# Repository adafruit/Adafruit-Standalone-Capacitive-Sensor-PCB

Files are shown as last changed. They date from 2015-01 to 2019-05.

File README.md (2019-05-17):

# Adafruit Standalone Capacitive Sensor PCBs

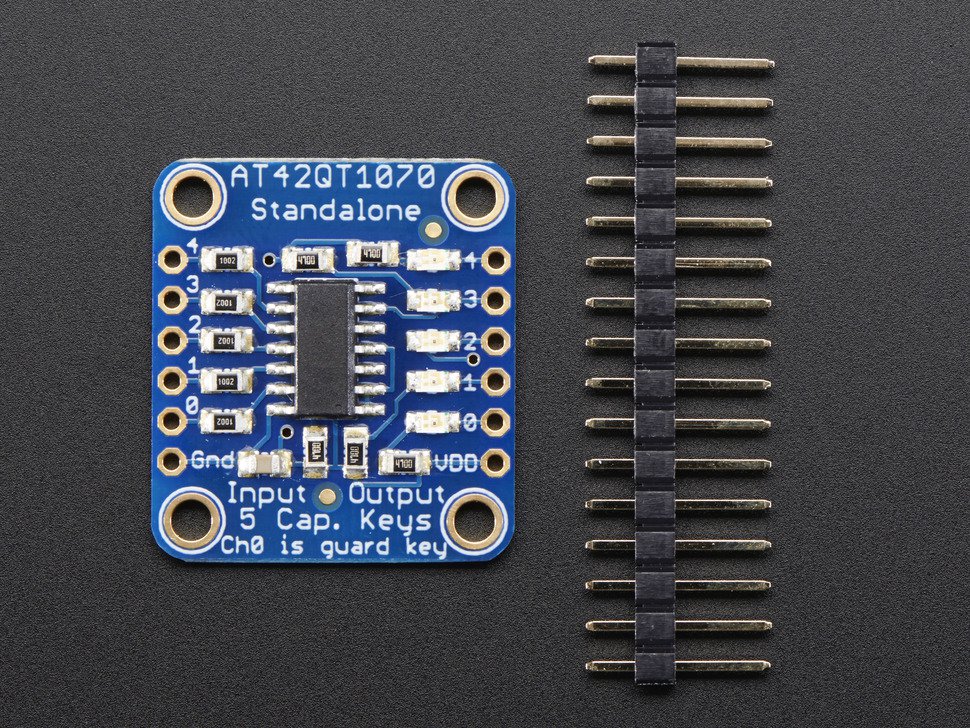
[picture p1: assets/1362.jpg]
&nbsp; 
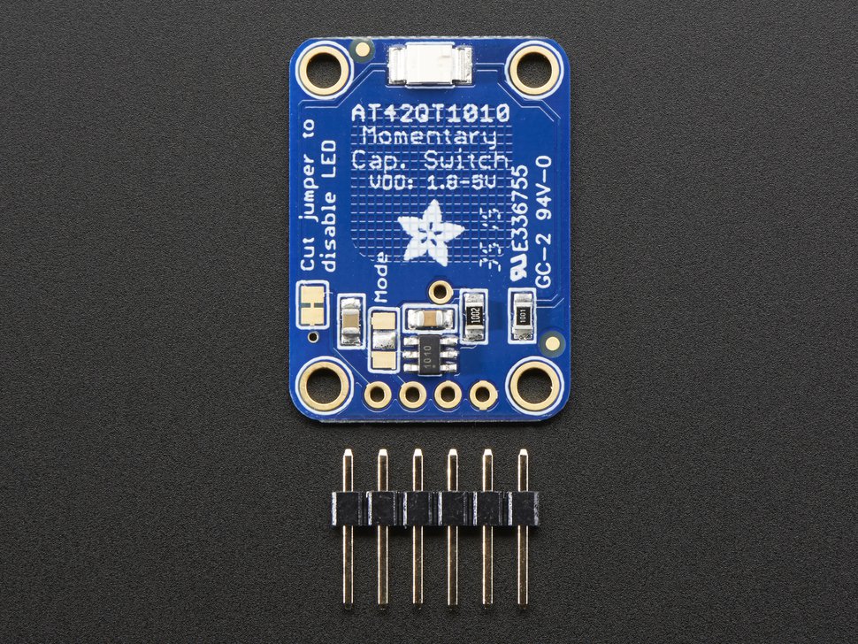
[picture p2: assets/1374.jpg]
&nbsp; 
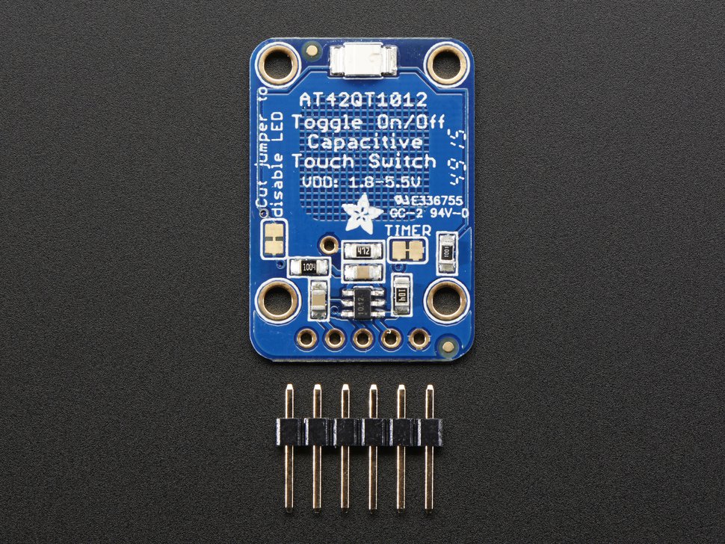
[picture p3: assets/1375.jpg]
<br />

Breakout boards for stand-alone capacitive touch sensors. These are the simplest ways to create projects with capacitive touch. No microcontroller is required here - just power with 1.8 to 5.5VDC. When a capacitive load is detected (e.g. a person touches one of the conductive contacts) the corresponding LED lights up and the output pin goes low. 

Format is EagleCAD schematic and board layout

For more details, check out the product pages at

-----> http://www.adafruit.com/products/1362

-----> http://www.adafruit.com/products/1374

-----> http://www.adafruit.com/products/1375

### License

Adafruit invests time and resources providing this open source design, please support Adafruit and open-source hardware by purchasing products from [Adafruit](https://www.adafruit.com)!

All text above must be included in any redistribution

Designed by Limor Fried/Ladyada for Adafruit Industries.
Creative Commons Attribution/Share-Alike, all text above must be included in any redistribution. 
See license.txt for additional information.

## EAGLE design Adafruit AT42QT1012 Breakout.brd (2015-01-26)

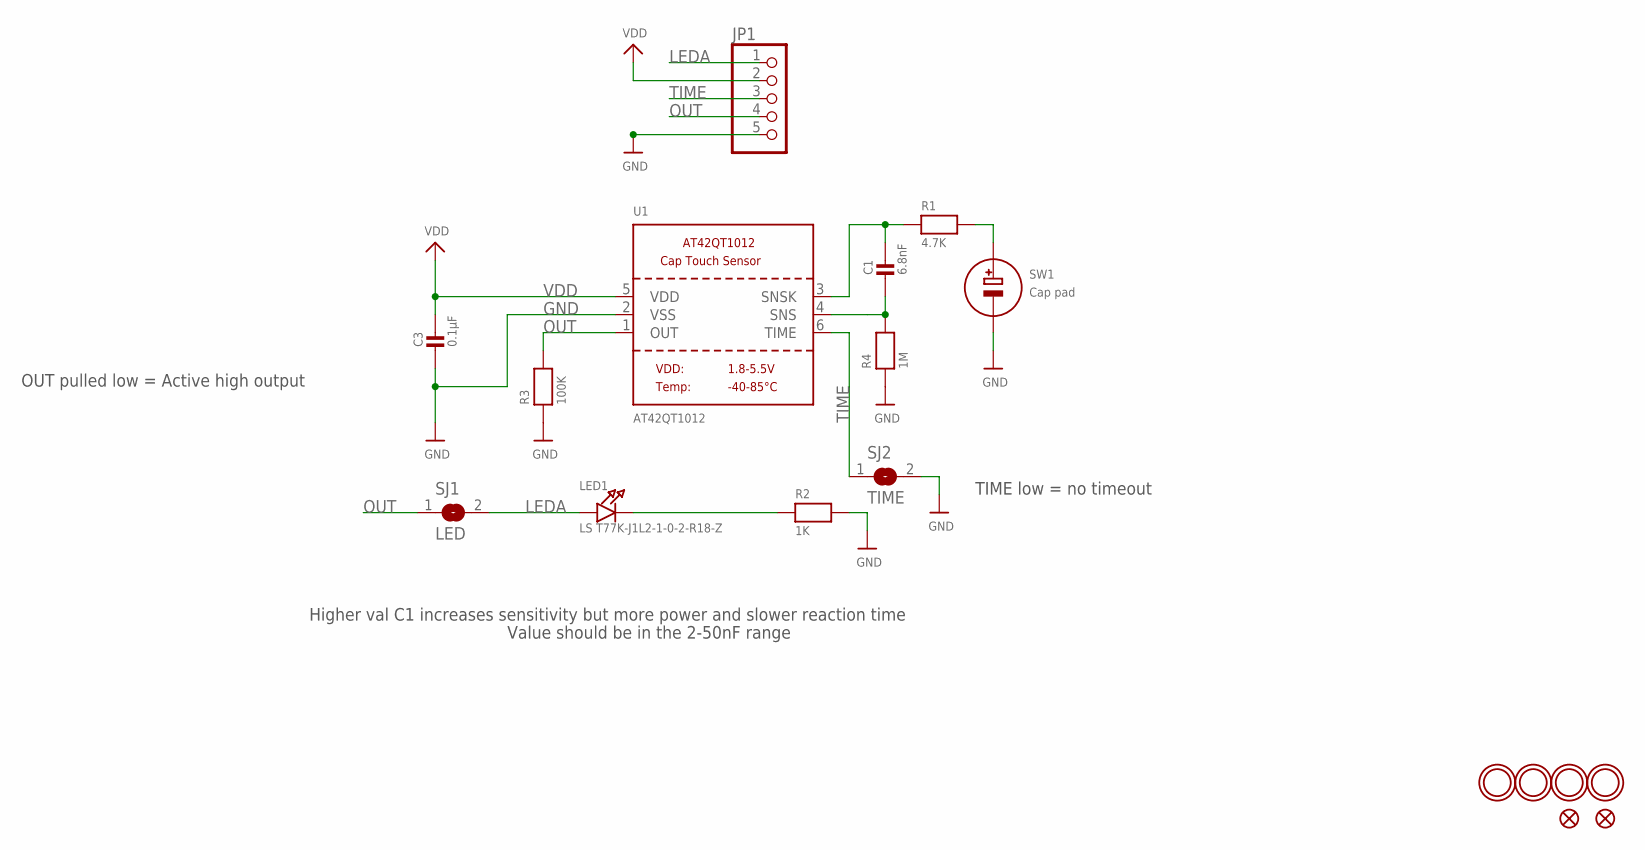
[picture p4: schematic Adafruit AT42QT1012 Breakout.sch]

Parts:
C1: 6.8nF; _0805
C3: 0.1µF; _0805
FID1, FID2: FIDUCIAL""; FIDUCIAL_1MM
JP1: HEADER-1X570MIL; 1X05_ROUND_70
LED1: LS T77K-J1L2-1-0-2-R18-Z; PLCC2_REVMOUNT
R1: 4.7K; _0805
R2: 1K; _0805
R3: 100K; _0805
R4: 1M; _0805
SJ1: LED; SOLDERJUMPER_CLOSEDWIRE
SJ2: TIME; SOLDERJUMPER_CLOSEDWIRE
SW1: Cap pad; CAPTOUCH_SIMPLE_12.5MM
U1: AT42QT1012; SOT23-6
U$6, U$9, U$10, U$11: MOUNTINGHOLE2.5; MOUNTINGHOLE_2.5_PLATED

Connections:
GND: C3.2, JP1.5, R2.2, R3.1, R4.1, SJ2.2, SW1.G (-), U1.2 (VSS)
LEDA: JP1.1, LED1.A, SJ1.2
unnamed: R1.2, SW1.E (+)
unnamed: C1.2, R4.2, U1.4 (SNS)
unnamed: C1.1, R1.1, U1.3 (SNSK)
unnamed: LED1.K (C), R2.1
OUT: JP1.4, R3.2, SJ1.1, U1.1 (OUT)
TIME: JP1.3, SJ2.1, U1.6 (TIME)
VDD: C3.1, JP1.2, U1.5 (VDD)

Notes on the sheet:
Higher val C1 increases sensitivity but more power and slower reaction time
Value should be in the 2-50nF range
OUT pulled low = Active high output
TIME low = no timeout

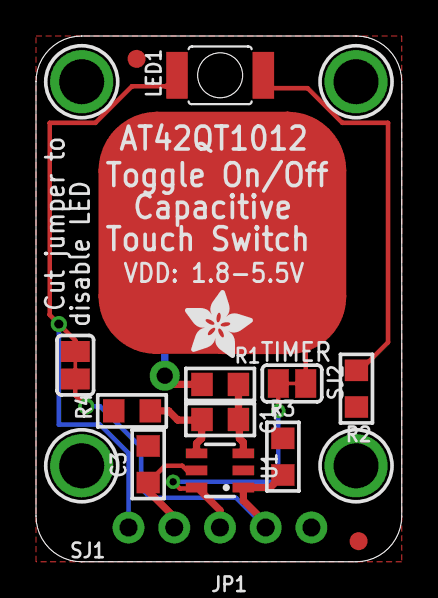
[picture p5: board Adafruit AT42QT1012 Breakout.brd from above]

Board: 2 copper layers, 20.3 x 29.2 mm, 19 parts (1 on the bottom side), 9 nets.

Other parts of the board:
U$12: ADAFRUIT_3.5MM

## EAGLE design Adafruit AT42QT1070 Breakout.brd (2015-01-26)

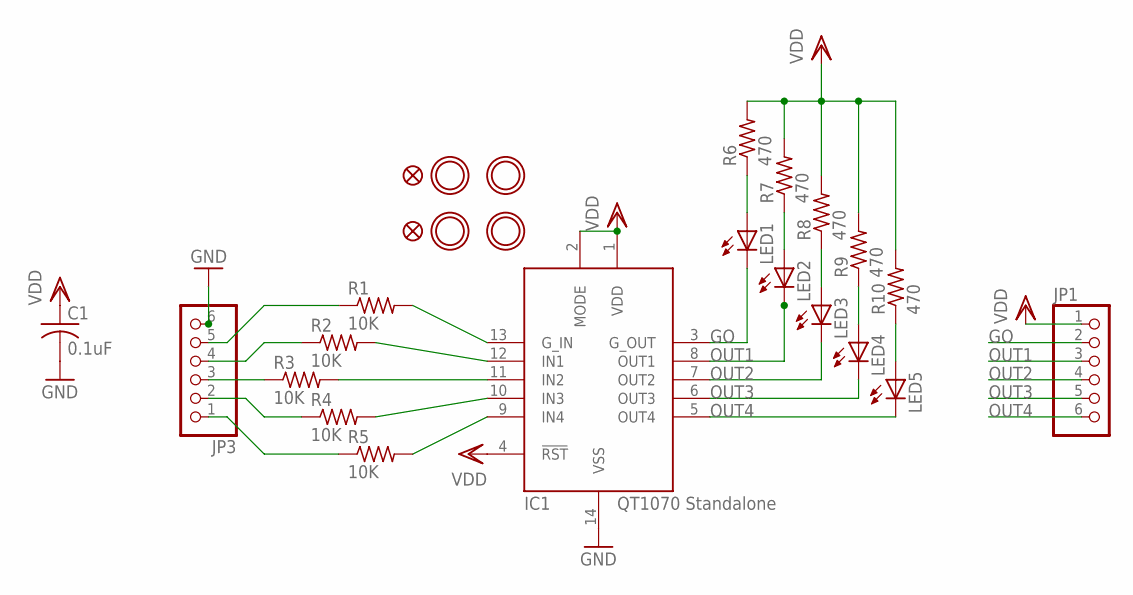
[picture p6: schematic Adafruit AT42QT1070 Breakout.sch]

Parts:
C1: 0.1uF; C0805K
FID1, FID2: FIDUCIAL""; FIDUCIAL_1MM
IC1: AT42QT1070-SSU; SO14
JP1, JP3: PINHD-1X6CB; 1X06-CLEANBIG
LED1, LED2, LED3, LED4, LED5: LEDCHIP-LED0805; CHIP-LED0805
R1, R2, R3, R4, R5: 10K; R0805
R6, R7, R8, R9, R10: 470; R0805
U$1, U$2, U$3, U$4: MOUNTINGHOLE2.5; MOUNTINGHOLE_2.5_PLATED

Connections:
GND: C1.2, IC1.14 (VSS), JP3.6
GO: IC1.3 (G_OUT), JP1.2, LED1.C
unnamed: IC1.13 (G_IN), R1.2
unnamed: IC1.12 (IN1), R2.2
unnamed: IC1.11 (IN2), R3.2
unnamed: IC1.10 (IN3), R4.2
unnamed: IC1.9 (IN4), R5.2
unnamed: JP3.5, R1.1
unnamed: JP3.4, R2.1
unnamed: JP3.3, R3.1
unnamed: JP3.2, R4.1
unnamed: JP3.1, R5.1
unnamed: LED1.A, R6.1
unnamed: LED2.A, R7.1
unnamed: LED3.A, R8.1
unnamed: LED4.A, R9.1
unnamed: LED5.A, R10.1
OUT1: IC1.8 (OUT1), JP1.3, LED2.C
OUT2: IC1.7 (OUT2), JP1.4, LED3.C
OUT3: IC1.6 (OUT3), JP1.5, LED4.C
OUT4: IC1.5 (OUT4), JP1.6, LED5.C
VDD: C1.1, IC1.1 (VDD), IC1.2 (MODE), IC1.4 (!RST), JP1.1, R6.2, R7.2, R8.2, R9.2, R10.2

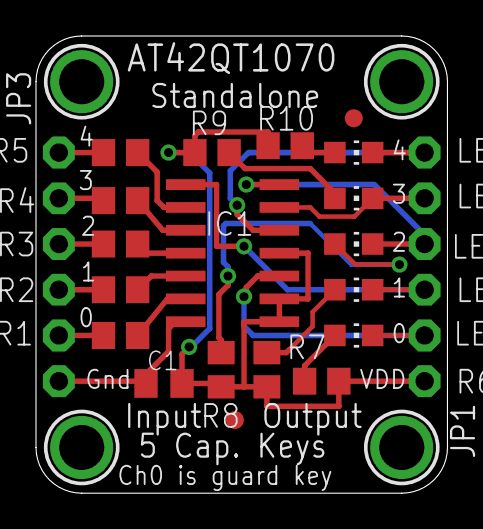
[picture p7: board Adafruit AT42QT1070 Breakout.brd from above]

Board: 2 copper layers, 22.9 x 25.4 mm, 26 parts (1 on the bottom side), 22 nets.

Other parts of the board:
U$6: ADAFRUIT_5MM

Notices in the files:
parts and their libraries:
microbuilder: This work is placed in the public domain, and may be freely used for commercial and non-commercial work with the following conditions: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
